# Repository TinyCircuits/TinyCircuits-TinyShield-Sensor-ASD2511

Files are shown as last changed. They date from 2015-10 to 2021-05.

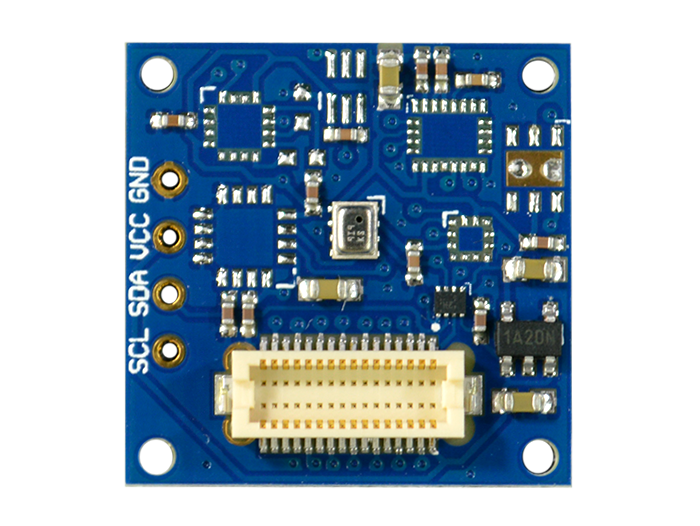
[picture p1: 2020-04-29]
images/tutorial_images_barometric-pressure/ASD2511-R-P-Tutorial-Image-01.png

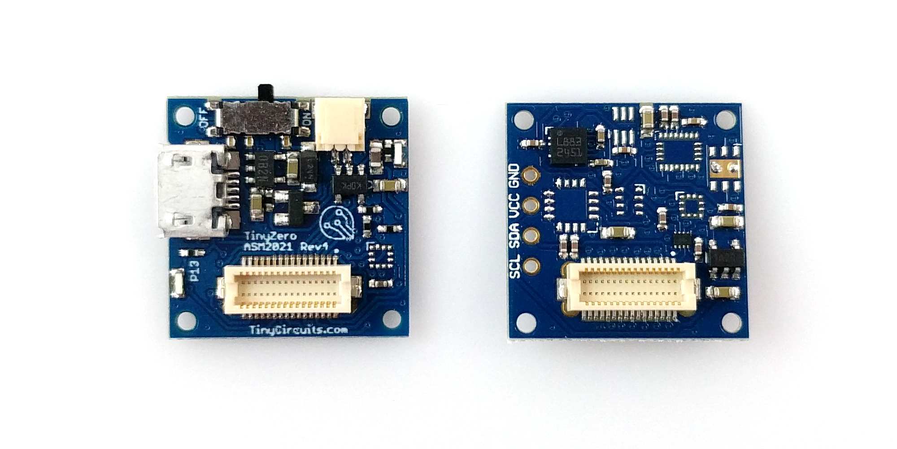
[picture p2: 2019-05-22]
images/tutorial_images_compass/ASD2511-R-C-Tutorial-Image-02.jpg

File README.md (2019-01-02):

# TinyCircuits TinyShield Sensor Board
# ASD2511 Rev5

The design files are located in the design_files/ folder for the TinyCircuits ASD2511 Rev 5 PCB.  This is a TinyShield board (Square Version, 20mm x 20mm) that has multiple sensor ICs on it and can be built under different configurations based on the sensor needs.  This board includes a 3-axis accelerometer, 3-axis gyroscope, 3-axis compass, 9-axis IMU, barometric pressure, temperature / humidity sensor, & ambient light sensor.  

Format is in Cadsoft Eagle format - Eagle version 6.2 was used for the original design.

For more infomation on this, check out the product pages for sensors at TinyCircuits.com: https://tinycircuits.com/collections/sensors/products/combo-sensor-tinyshield

#License:

Design by TinyCircuits.
All design files are released under the Creative Commons Attribution Share-Alike 3.0 License, see the following link for details: http://creativecommons.org/licenses/by-sa/3.0

All text above must be included in any redistribution or derived design

This project uses designs and concepts developed as part of the Arduino project and the LilyPad project.  The TinyCircuits design files themselves (schematics, PCB and libraries) are not directly derived from these works' design files and have been created new, however the concepts and basic architecture behind the TinyDuino and TinyLily products are derived and we thank the hard work of the organizations below for their contributions to open-source hardware:
  
Original Arduino Uno Design by Team Arduino

LilyPad Arduino Design by Leah Buechley and Sparkfun Electronics

Please support the open-source hardware community

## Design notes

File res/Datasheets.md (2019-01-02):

## Datasheets

LSM9DS1: https://www.st.com/resource/en/datasheet/lsm9ds1.pdf

Si7020: https://www.silabs.com/products/sensors/humidity/si7006-13-20-21-34

BMP280: https://ae-bst.resource.bosch.com/media/_tech/media/datasheets/BST-BMP280-DS001.pdf

TSL2572: http://ams.com/documents/20143/36005/TSL2572_DS000178_3-00.pdf/48392d43-48b1-e4cd-8272-40ab48727830

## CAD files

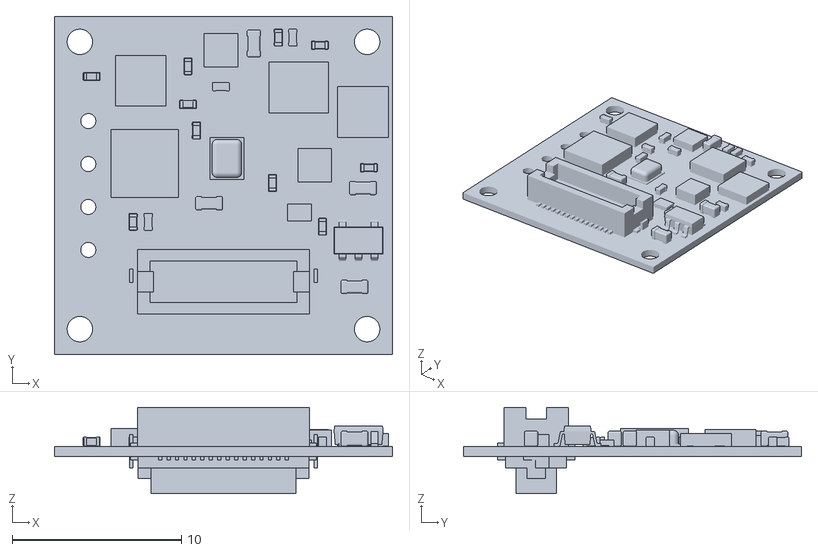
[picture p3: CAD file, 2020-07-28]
cad/TinyShield_SENSOR_BOARD_ASD2511_REV5-STL.stl
20.0 x 20.0 x 5.10

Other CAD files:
cad/TinyShield_SENSOR_BOARD_ASD2511_REV5-DETAILED_DRAWING-DXF.dxf

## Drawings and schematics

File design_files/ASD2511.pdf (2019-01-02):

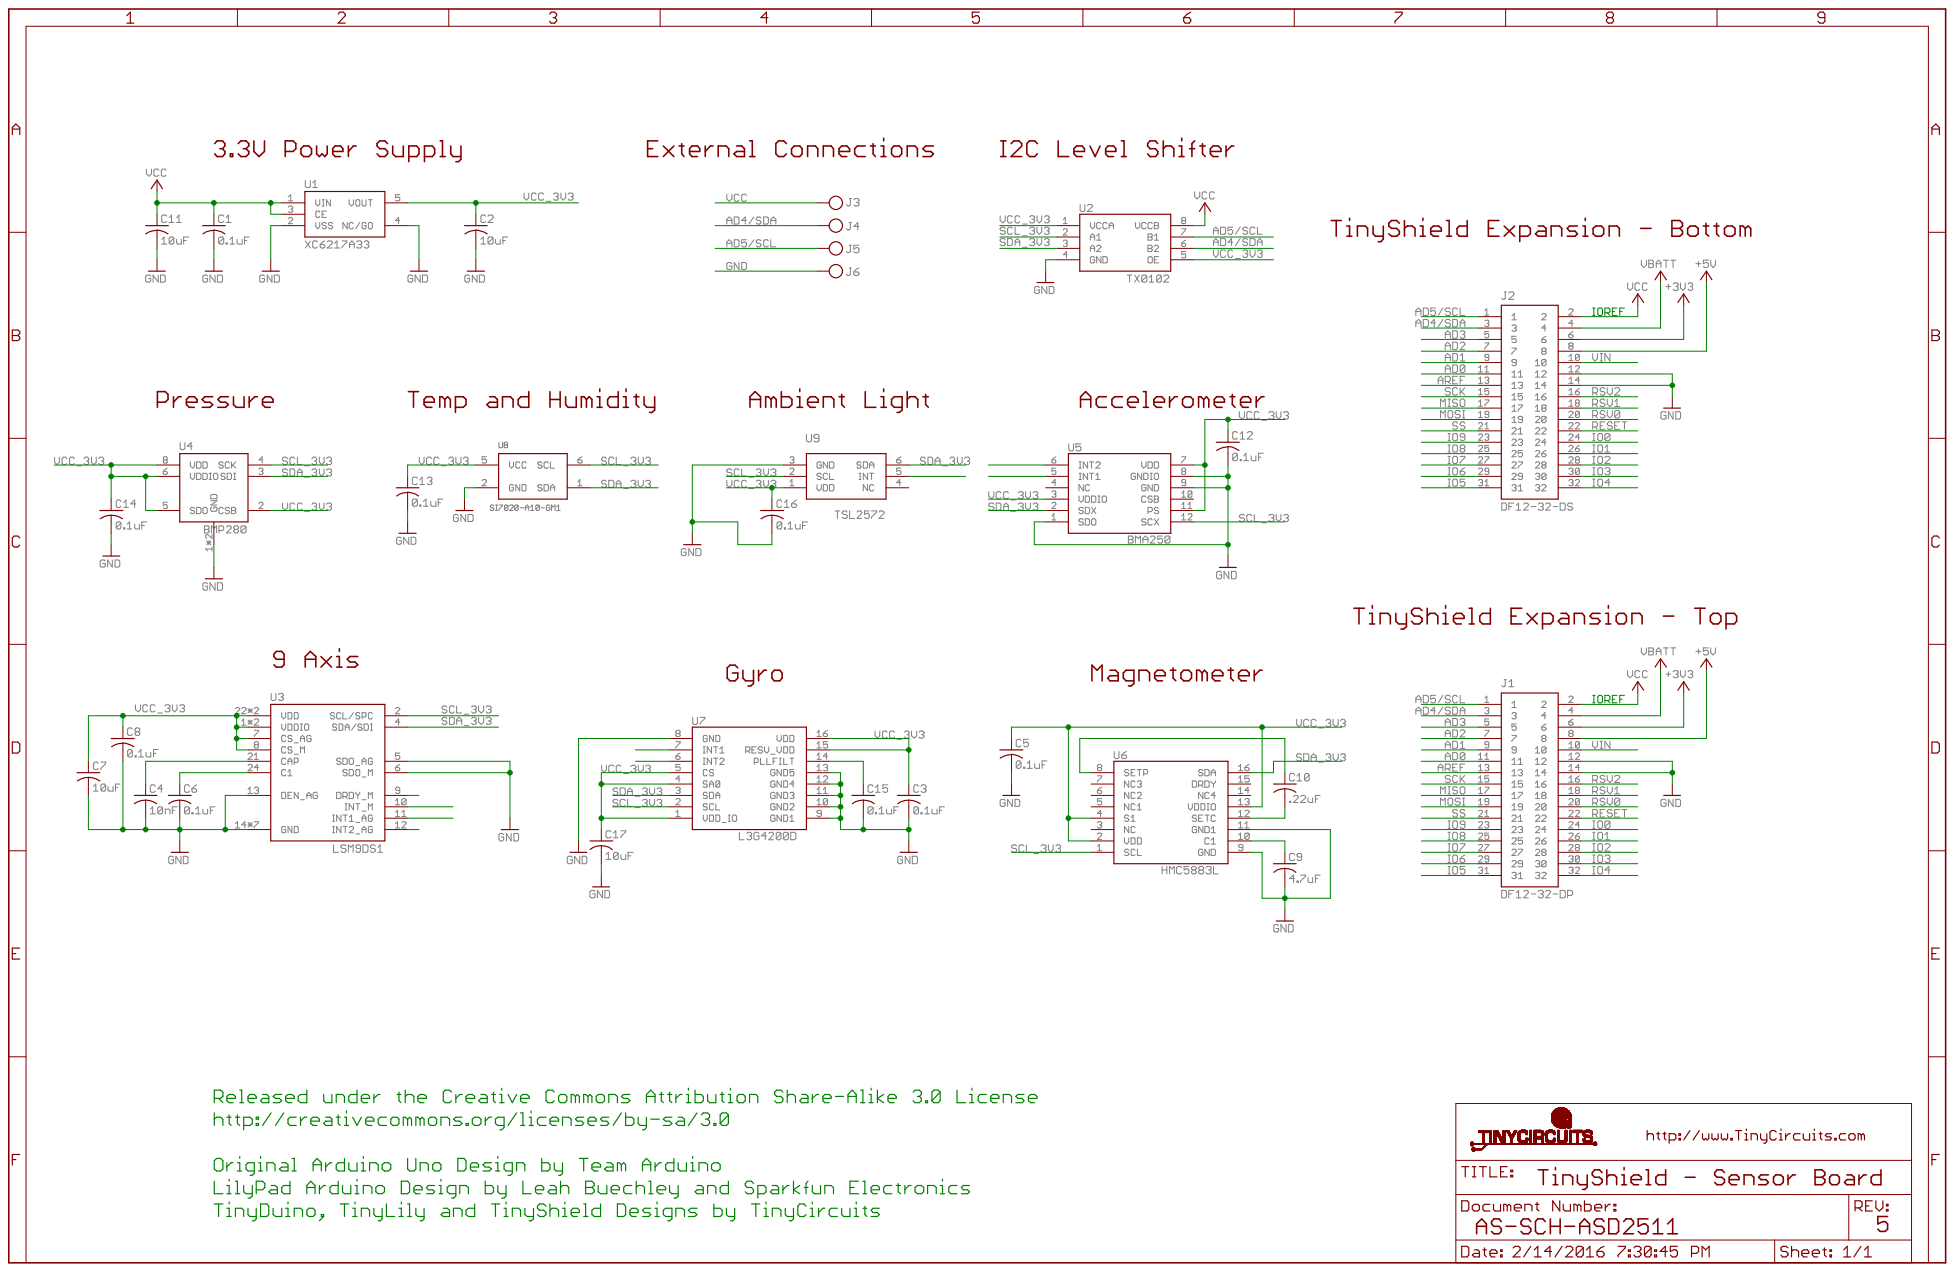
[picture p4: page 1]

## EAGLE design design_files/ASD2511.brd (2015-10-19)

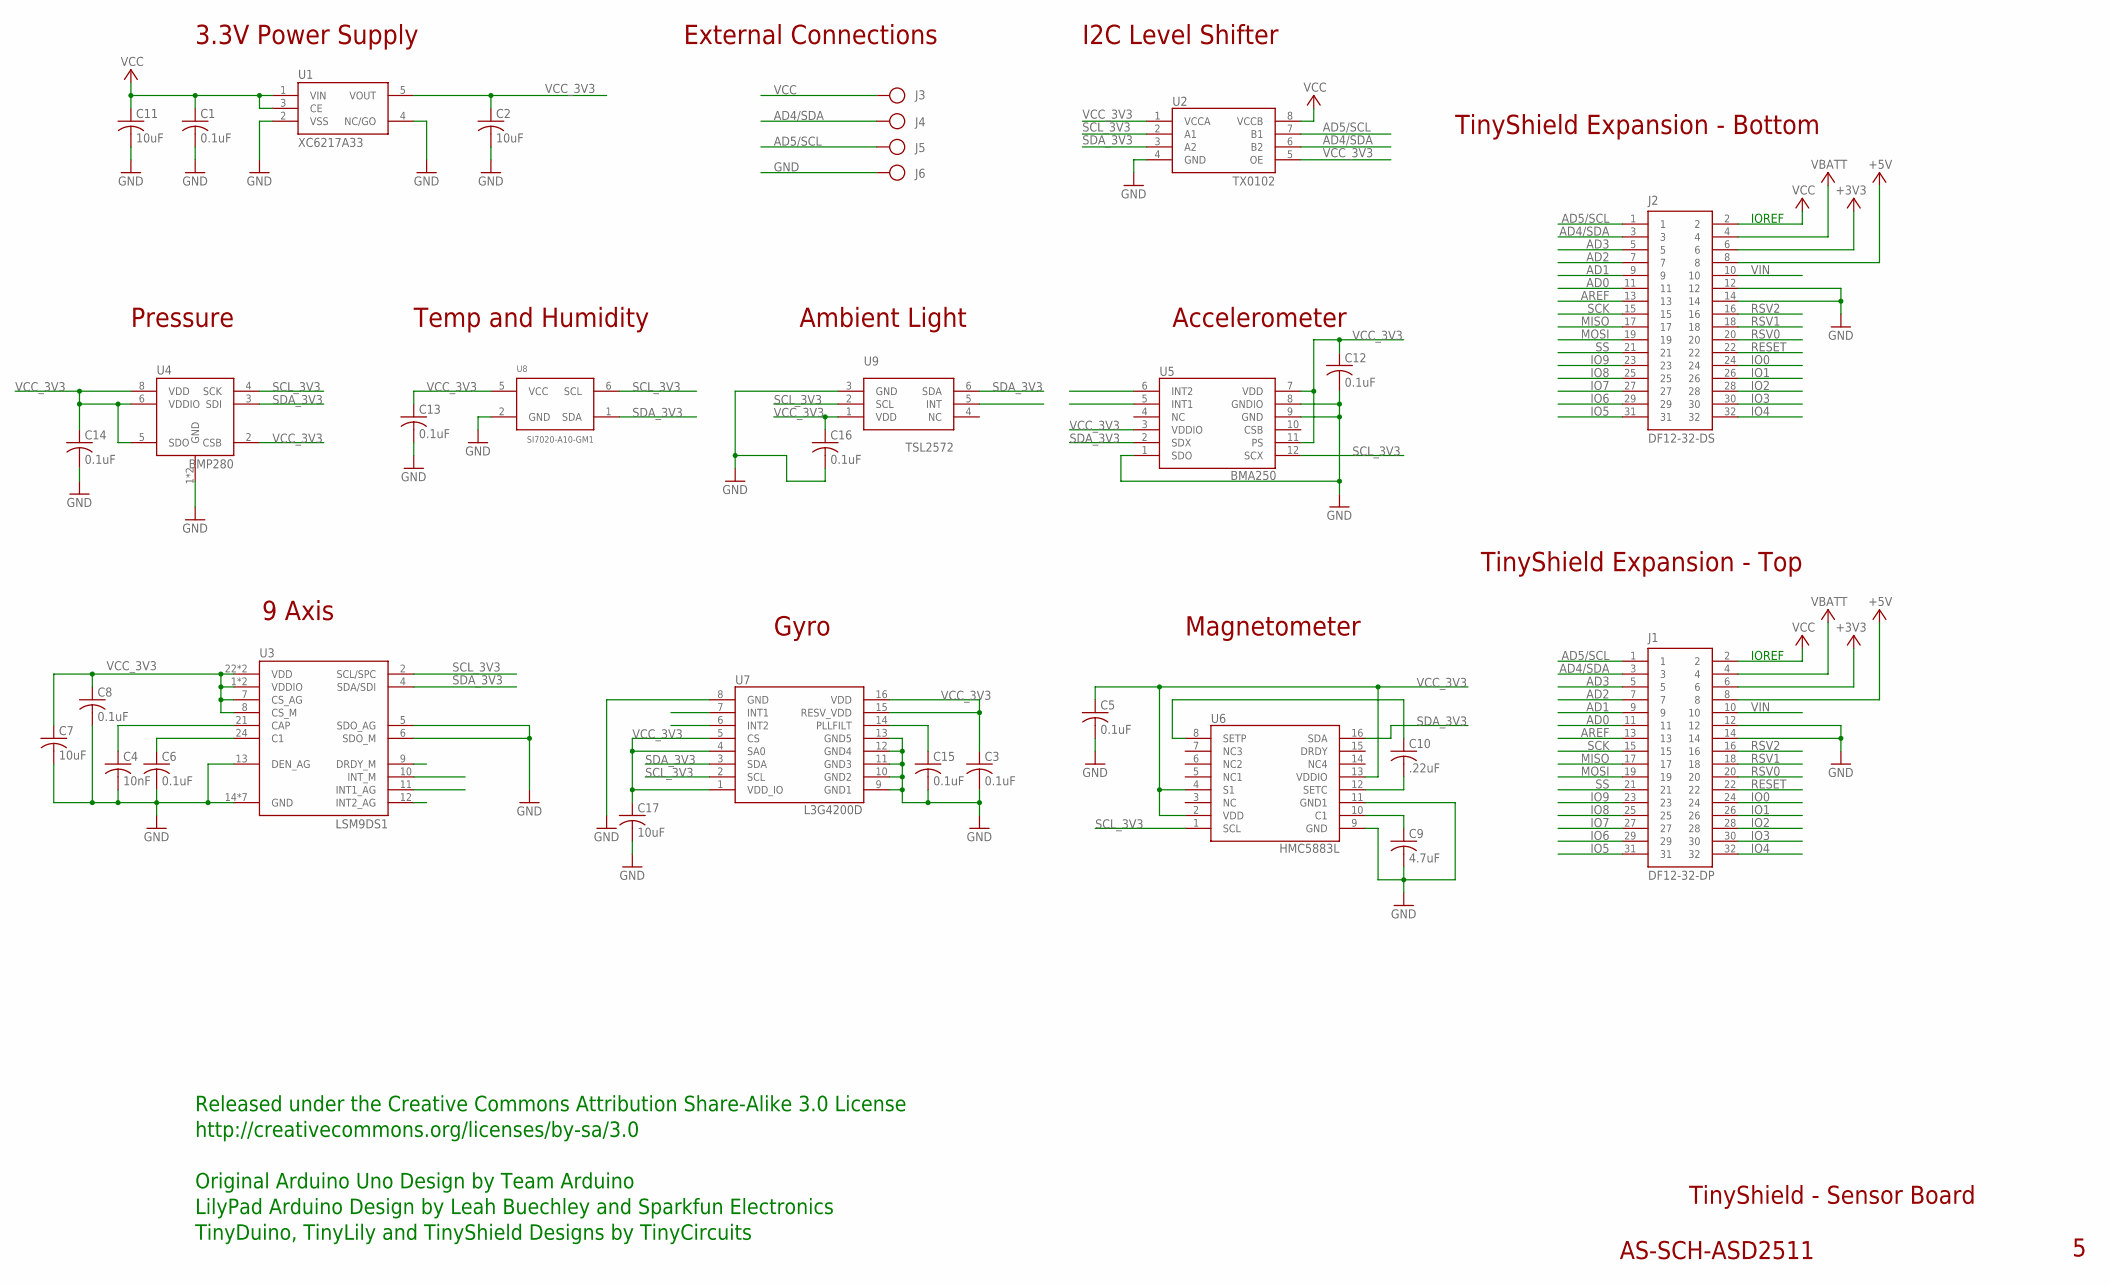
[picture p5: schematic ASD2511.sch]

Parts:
C1, C3, C5, C8, C12, C13, C14, C15, C16: 0.1uF; C0402; PARTNO AS-ITM-00008
C2, C7: 10uF; C0603; PARTNO AS-ITM-00002
C4: 10nF; C0402
C6: 0.1uF; C0402
C9: 4.7uF; C0402; PARTNO AS-ITM-00242
C10: .22uF; C0402
C11, C17: 10uF; C0603
J1: DF12-32-DP; PARTNO AS-ITM-00015
J2: DF12-32-DS; PARTNO AS-ITM-00012
J3, J4, J5, J6: PIN_1X.1"1; 1X.1"_2
U1: XC6217A33; SOT-25; PARTNO AS-ITM-00249
U2: TX0102; DQE(R-PX2SON-N8)
U3: LSM9DS1; LGA-24
U4: BMP280
U5: BMA250; 3-AXIS_ACCELEROMETER
U6: HMC5883L
U7: L3G4200D
U8: SI7020-A10-GM1; DFN6
U9: TSL2572

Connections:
+3V3: J1.6, J2.6
+5V: J1.8, J2.8
AD0: J1.11, J2.11
AD1: J1.9, J2.9
AD2: J1.7, J2.7
AD3: J1.5, J2.5
AD4/SDA: J1.3, J2.3, J4.1, U2.6 (B2)
AD5/SCL: J1.1, J2.1, J5.1, U2.7 (B1)
AREF: J1.13, J2.13
GND: C1.2, C2.2, C3.2, C4.2, C5.2, C6.2, C7.2, C8.2, C9.2, C11.2, C12.2, C13.2, C14.2, C15.2, C16.2, C17.2, J1.12, J1.14, J2.12, J2.14, J6.1, U1.2 (VSS), U1.4 (NC/GO), U2.4 (GND), U3.5 (SDO_AG), U3.6 (SDO_M), U3.13 (DEN_AG), U3.14 (GND), U3.15 (GND), U3.16 (GND), U3.17 (GND), U3.18 (GND), U3.19 (GND), U3.20 (GND), U4.1 (GND), U4.7 (GND), U5.1 (SDO), U5.8 (GNDIO), U5.9 (GND), U6.9 (GND), U6.11 (GND1), U7.8 (GND), U7.9 (GND1), U7.10 (GND2), U7.11 (GND3), U7.12 (GND4), U7.13 (GND5), U8.2 (GND), U9.3 (GND)
IO0: J1.24, J2.24
IO1: J1.26, J2.26
IO2: J1.28, J2.28
IO3: J1.30, J2.30
IO4: J1.32, J2.32
IO5: J1.31, J2.31
IO6: J1.29, J2.29
IO7: J1.27, J2.27
IO8: J1.25, J2.25
IO9: J1.23, J2.23
MISO: J1.17, J2.17
MOSI: J1.19, J2.19
unnamed: C4.1, U3.21 (CAP)
unnamed: C15.1, U7.14 (PLLFILT)
unnamed: C9.1, U6.10 (C1)
unnamed: C6.1, U3.24 (C1)
unnamed: C10.2, U6.12 (SETC)
unnamed: C10.1, U6.8 (SETP)
RESET: J1.22, J2.22
RSV0: J1.20, J2.20
RSV1: J1.18, J2.18
RSV2: J1.16, J2.16
SCK: J1.15, J2.15
SCL_3V3: U2.2 (A1), U3.2 (SCL/SPC), U4.4 (SCK), U5.12 (SCX), U6.1 (SCL), U7.2 (SCL), U8.6 (SCL), U9.2 (SCL)
SDA_3V3: U2.3 (A2), U3.4 (SDA/SDI), U4.3 (SDI), U5.2 (SDX), U6.16 (SDA), U7.3 (SDA), U8.1 (SDA), U9.6 (SDA)
SS: J1.21, J2.21
VBATT: J1.4, J2.4
VCC: C1.1, C11.1, J1.2, J2.2, J3.1, U1.1 (VIN), U1.3 (CE), U2.8 (VCCB)
VCC_3V3: C2.1, C3.1, C5.1, C7.1, C8.1, C12.1, C13.1, C14.1, C16.1, C17.1, U1.5 (VOUT), U2.1 (VCCA), U2.5 (OE), U3.1 (VDDIO), U3.3 (VDDIO), U3.7 (CS_AG), U3.8 (CS_M), U3.22 (VDD), U3.23 (VDD), U4.2 (CSB), U4.5 (SDO), U4.6 (VDDIO), U4.8 (VDD), U5.3 (VDDIO), U5.7 (VDD), U5.11 (PS), U6.2 (VDD), U6.4 (S1), U6.13 (VDDIO), U7.1 (VDD_IO), U7.4 (SA0), U7.5 (CS), U7.15 (RESV_VDD), U7.16 (VDD), U8.5 (VCC), U9.1 (VDD)
VIN: J1.10, J2.10

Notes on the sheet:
TinyShield Expansion - Bottom
TinyShield - Sensor Board
AS-SCH-ASD2511
TinyShield Expansion - Top
IOREF
Released under the Creative Commons Attribution Share-Alike 3.0 License
http://creativecommons.org/licenses/by-sa/3.0
LilyPad Arduino Design by Leah Buechley and Sparkfun Electronics
TinyDuino, TinyLily and TinyShield Designs by TinyCircuits
Original Arduino Uno Design by Team Arduino
External Connections
3.3V Power Supply
I2C Level Shifter
9 Axis
Pressure
Temp and Humidity
Ambient Light
Accelerometer
Gyro
Magnetometer

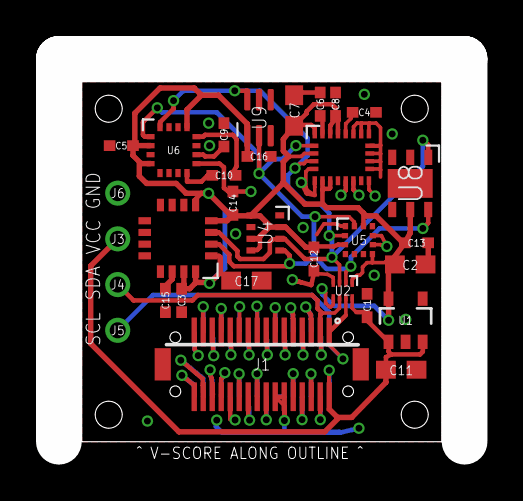
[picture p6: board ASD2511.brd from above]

Board: 2 copper layers, 20.0 x 20.0 mm, 33 parts (1 on the bottom side), 40 nets.

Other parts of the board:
U$1: DOCFIELD-TINYCIRCUITS-PCB

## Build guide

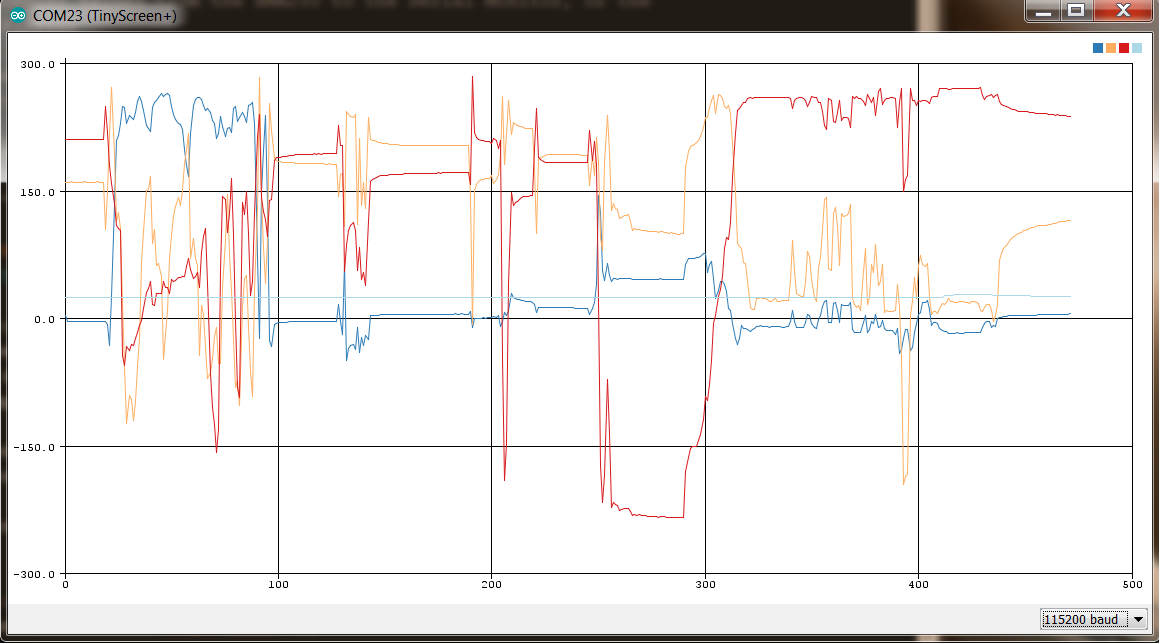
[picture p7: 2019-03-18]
images/tutorial_images_accelerometer/ASD2511-R-A-Tutorial-Image-06.png

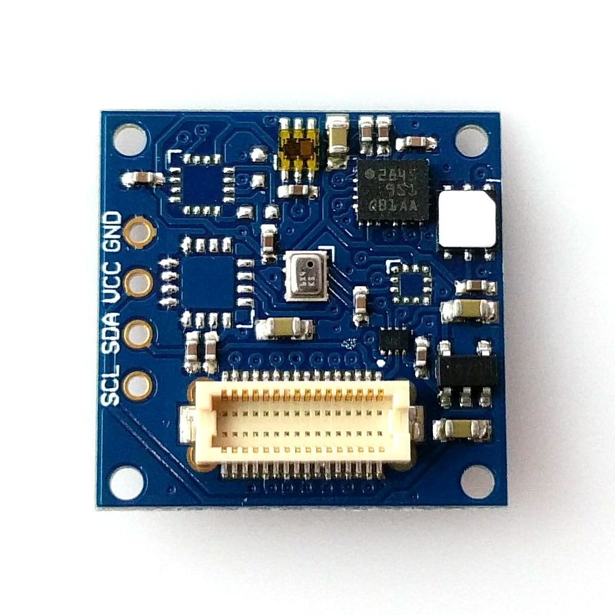
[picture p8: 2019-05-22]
images/tutorial_images_combo/ASD2511-R-N-T-P-L-Tutorial-Image-01.jpg

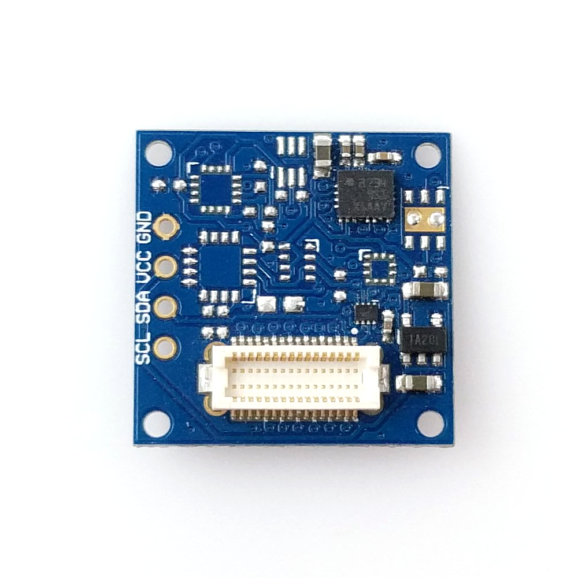
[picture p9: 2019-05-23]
images/tutorial_images_9-axis/ASD2511-R-N-Tutorial-Image-01.jpg

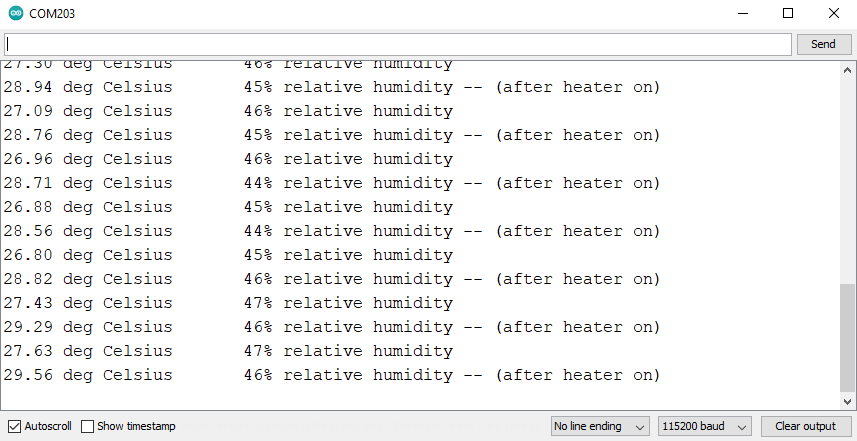
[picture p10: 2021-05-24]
images/tutorial_images_temperature-humidity/ASD2511-R-T-Tutorial-Image-05.png

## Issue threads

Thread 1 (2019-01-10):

No need to wait after Wire.requestFrom() and no need to clear the buffer.

Koepel, 2019-01-10:
In the file "TinyCircuits-TinyShield-Sensor-ASD2511/libraries/SI7021/SI7021.cpp" you may remove these lines (at the moment line 105 and 106):
```
while(Wire.available() < reglen) {
}
```
Explanation: [Common-mistakes#1](https://github.com/Koepel/How-to-use-the-Arduino-Wire-library/wiki/Common-mistakes#1)

At the LowPowerLab I have [issued the same problem](https://github.com/LowPowerLab/SI7021/issues/12), and they [fixed it](https://github.com/LowPowerLab/SI7021/blob/master/SI7021.cpp).

---

I spotted the same problem in "TinyCircuits-TinyShield-Sensor-ASD2511/examples/TinyShield_BarometricPressure/BMP280.cpp". The waiting after a `Wire.requestFrom()` can be removed (currently at line 129).

---

In the files:
 - TinyCircuits-TinyShield-Sensor-ASD2511/examples/TinyShield_9_Axis_Sensorboard/RTIMULSM9DS1.cpp
 - TinyCircuits-TinyShield-Sensor-ASD2511/examples/TinyShield_9_Axis_Sensorboard/RTIMUMPU9150.cpp
 -  TinyCircuits-TinyShield-Sensor-ASD2511/libraries/RTIMULib/RTIMUMPU9150.cpp

in the functions `I2CReadByte()` and `I2CReadBytes()`, the buffer is cleared after a Wire.endTransmission:
```
while(Wire.available())
  Wire.read();
```
Those lines can be removed as well.
Explanation: [Common-mistakes#4](https://github.com/Koepel/How-to-use-the-Arduino-Wire-library/wiki/Common-mistakes#4)

Closed 2019-01-10.

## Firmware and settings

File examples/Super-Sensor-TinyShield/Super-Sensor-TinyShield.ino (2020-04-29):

/************************************************************************
 * Combo Sensor TinyShield Example Program
 * 
 * This program utilizes all sensors on the Combo Sensor TinyShield and
 * prints the data to the Serial Monitor.
 *
 * Hardware by: TinyCircuits
 * Written by: Hunter Hykes for TinyCircuits
 *
 * Initiated: 01/14/2020
 * Updated: 01/14/2020
 ************************************************************************/

#include <Wire.h>
#include "RTIMUSettings.h"  // 9-Axis
#include "RTIMU.h"          // 9-Axis
#include "RTFusionRTQF.h"   // 9-Axis
#include <SI7021.h>         // Temp/Hum
#include "BMP280.h"         // Pressure Sensor

#ifndef ARDUINO_ARCH_SAMD
#include <EEPROM.h>
#endif

// Make compatible with all TinyCircuits processors
#if defined(ARDUINO_ARCH_AVR)
#define SerialMonitorInterface Serial
#elif defined(ARDUINO_ARCH_SAMD)
#define SerialMonitorInterface SerialUSB
#endif

// sets the rate at which results are displayed
#define DISPLAY_INTERVAL 10000    // interval between SerialMonitorInterface updates
#define  SERIAL_PORT_SPEED 115200 // defines the speed to use for the debug serial port

/* * * * * * * * * * * * 9-Axis Sensor * * * * * * * * * * * */
RTIMU *imu;               // the IMU object
RTFusionRTQF fusion;      // the fusion object
RTIMUSettings settings;   // the settings object
unsigned long lastDisplay;
unsigned long lastRate;
int sampleCount;
unsigned long delta;
unsigned long now = millis();
RTVector3 accelData;    // for storing 9-Axis accelerometer data
RTVector3 gyroData;     // for storing 9-Axis gyroscope data
RTVector3 compassData;  // for storing 9-Axis compass data
RTVector3 fusionData;   // for storing 9-Axis fusion data

/* * * * * * * * * * * Temp/Hum Sensor * * * * * * * * * * */
SI7021 sensor;        // Temp/Hum Sensor Object
int celcius;          // temperature data
int relativeHumidity; // humidity data

/* * * * * * * *  ** * Pressure Sensor * * * * * * * * * * */
#define P0 1013.25
BMP280 bmp;
bool PrintPressure = true; // if true, pressure values will be printed
double T, A, P; // temperature, altitude, and pressure value readings

/* * * * * * * * * Ambient Light Sensor * * * * * * * * * */
#define TSL2572_I2CADDR 0x39 // address of ambient light sensor

#define GAIN_1X 0
#define GAIN_8X 1
#define GAIN_16X 2
#define GAIN_120X 3

#define GAIN_DIVIDE_6 true //only use this with 1x and 8x gain settings
int gain_val = 0;

float AmbientLightLux;  // Illuminance value reading


void setup() {
  imu = RTIMU::createIMU(&settings);  // 9-Axis object

  SerialMonitorInterface.begin(SERIAL_PORT_SPEED); // Setup the Serial Monitor to operate at the specified Baud rate
  while (!SerialMonitorInterface); // do nothing until the Serial Monitor is opened

  Wire.begin(); // start I2C communications

  init9axis();          // initialize the 9-axis sensor
  initTempSensor();     // initialize the temperature and humidity sensor
  initPressSensor();    // initialize the pressure sensor
  TSL2572init(GAIN_1X); // initialize the illuminance sensor

  SerialMonitorInterface.println("\n- - - - - - - - - - - - - - - - - - - - - - - - - - - - - -");
  SerialMonitorInterface.println("\t\t\tEND OF SETUP\t\t\t");
  SerialMonitorInterface.println("- - - - - - - - - - - - - - - - - - - - - - - - - - - - - -");
}

void loop() {
  /* * * * * * * * * * 9-Axis * * * * * * * * * */
  read9axis();
  //printAccel();
  //printGyro();
  //printMag();
  printFused();

  /* * * * * * * * * * Temp/Hum * * * * * * * * * */
  readTempSensor();
  printTempSensor();

  /* * * * * * * * * * Pressure * * * * * * * * * */
  readPressSensor();

  /* * * * * * * * * * Light * * * * * * * * * */
  AmbientLightLux = Tsl2572ReadAmbientLight();
  printLight();

  SerialMonitorInterface.println("\n- - - - - - - - - - - - - - - - - - - - - - - - - - - - - -\n");

  //delay(DISPLAY_INTERVAL); // wait some predetermined time before printing the next set of samples
}

// initialize the 9-Axis sensor
void init9axis() {
  int errcode;

  SerialMonitorInterface.print("Initializing 9-Axis..."); SerialMonitorInterface.println(imu->IMUName());
  if ((errcode = imu->IMUInit()) < 0) {
    SerialMonitorInterface.print("\t9-Axis Init Failed!"); SerialMonitorInterface.println(errcode);
  }

  if (imu->getCalibrationValid())
    SerialMonitorInterface.println("\tUsing compass calibration");
  else
    SerialMonitorInterface.println("\tNo valid compass calibration data");

  lastDisplay = lastRate = millis();
  sampleCount = 0;

  // Slerp power controls the fusion and can be between 0 and 1
  // 0 means that only gyros are used, 1 means that only accels/compass are used
  // In-between gives the fusion mix.
  fusion.setSlerpPower(0.02);

  // use of sensors in the fusion algorithm can be controlled here
  // change any of these to false to disable that sensor
  fusion.setGyroEnable(true);
  fusion.setAccelEnable(true);
  fusion.setCompassEnable(true);
}

// read values from 9-Axis and update variables
void read9axis() {
  now = millis();

  if (imu->IMURead()) {                                // get the latest data if ready yet
    fusion.newIMUData(imu->getGyro(), imu->getAccel(), imu->getCompass(), imu->getTimestamp());
    sampleCount++;
    if ((delta = now - lastRate) >= 1000) {
      SerialMonitorInterface.print("Sample rate: "); SerialMonitorInterface.print(sampleCount);
      if (imu->IMUGyroBiasValid())
        SerialMonitorInterface.println(", gyro bias valid");
      else
        SerialMonitorInterface.println(", calculating gyro bias - don't move IMU!!");

      sampleCount = 0;
      lastRate = now;
    }

    accelData = imu->getAccel();
    gyroData = imu->getGyro();
    compassData = imu->getCompass();
    fusionData = fusion.getFusionPose();
  }
}

// initialize the temperature/humidity sensor
void initTempSensor() {
  SerialMonitorInterface.println("Initializing Temp/Hum Sensor... ");
  if (!sensor.begin()) {
    SerialMonitorInterface.println("\tSI7021 Init Failed!");
    while (true);
  }
  SerialMonitorInterface.println("\tSuccess!");
}

// read values from temperature/humidity sensor and update variables
void readTempSensor() {
  celcius = sensor.getCelsiusHundredths() / 100;
  relativeHumidity = sensor.getHumidityPercent();
}

// print temperature/humidity sensor variables to SerialMonitorInterface
void printTempSensor() {
  SerialMonitorInterface.println("\nTEMPERATURE DATA");
  SerialMonitorInterface.print(celcius);
  SerialMonitorInterface.print("°C\t");
  SerialMonitorInterface.print(relativeHumidity);
  SerialMonitorInterface.println("% Humidity");
}

// print 9-Axis accelerometer values to SerialMonitorInterface
void printAccel() {
  SerialMonitorInterface.println("\nACCELEROMETER DATA");
  displayAxis("Accel: ", accelData.x(), accelData.y(), accelData.z());        // accel data
}

// print 9-Axis gyroscope values to SerialMonitorInterface
void printGyro() {
  SerialMonitorInterface.println("\nGYROSCOPE DATA");
  displayAxis("Gyro: ", gyroData.x(), gyroData.y(), gyroData.z());            // gyro data
}

// print 9-Axis magnetometer values to SerialMonitorInterface
void printMag() {
  SerialMonitorInterface.println("\nMAGNETOMETER DATA");
  displayAxis("Mag: ", compassData.x(), compassData.y(), compassData.z());    // compass data
}

// print 9-Axis fused data values to SerialMonitorInterface
void printFused() {
  SerialMonitorInterface.println("\nFUSED DATA");
  displayDegrees("Pose: ", fusionData.x(), fusionData.y(), fusionData.z());   // fused output
}

// prints the specified data label followed by the provided x, y, z values
void displayAxis(const char *label, float x, float y, float z) {
  SerialMonitorInterface.print(label);
  SerialMonitorInterface.print("\tx: "); SerialMonitorInterface.println(x);
  SerialMonitorInterface.print("\ty: "); SerialMonitorInterface.println(y);
  SerialMonitorInterface.print("\tz: "); SerialMonitorInterface.println(z);
}

// prints the specified data label followed by the provided x, y, z values (but in degrees)
void displayDegrees(const char *label, float x, float y, float z) {
  SerialMonitorInterface.print(label);
  SerialMonitorInterface.print("\tx: "); SerialMonitorInterface.println(x * RTMATH_RAD_TO_DEGREE);
  SerialMonitorInterface.print("\ty: "); SerialMonitorInterface.println(y * RTMATH_RAD_TO_DEGREE);
  SerialMonitorInterface.print("\tz: "); SerialMonitorInterface.println(z * RTMATH_RAD_TO_DEGREE);
}

// initialize the pressure sensor
void initPressSensor() {
  SerialMonitorInterface.println("Initializing Pressure Sensor... ");

  if (!bmp.begin()) {
    SerialMonitorInterface.println("\tBMP Init Failed!");
    while (1);
  }
  else SerialMonitorInterface.println("\tSuccess!");

  bmp.setOversampling(4);
}

// read values from pressure sensor and update variables
void readPressSensor() {
  char result = bmp.startMeasurment();

  if (result != 0) {
    delay(result);
    result = bmp.getTemperatureAndPressure(T, P);

    if (result != 0) {
      A = bmp.altitude(P, P0);

      printPressSensorPressure();
      printPressSensorTemperature();
      printPressSensorAltitude();
    } else {
      int debug = bmp.getError();
      SerialMonitorInterface.println(String(debug));
    }
  } else {
    SerialMonitorInterface.println("\nPressure Sensor Error.");
  }
}

// print barometric pressure value to SerialMonitorInterface
void printPressSensorPressure() {
  SerialMonitorInterface.println("\nPRESSURE DATA");
  SerialMonitorInterface.print("P = "); SerialMonitorInterface.print(P, 2); SerialMonitorInterface.println(" mBar\t");
}

// print temperature value (from pressure sensor) to SerialMonitorInterface
void printPressSensorTemperature() {
  SerialMonitorInterface.println("\nTEMPERATURE DATA (PRESSURE SENSOR)");
  SerialMonitorInterface.print("T = "); SerialMonitorInterface.print(T, 2); SerialMonitorInterface.println("°C\t");
}

// print altitude value to SerialMonitorInterface
void printPressSensorAltitude() {
  SerialMonitorInterface.println("\nALTITUDE DATA");
  SerialMonitorInterface.print("A = "); SerialMonitorInterface.print(A, 2); SerialMonitorInterface.println(" m");
}

// initialize the ambient light sensor
void TSL2572init(uint8_t gain) {
  Tsl2572RegisterWrite( 0x0F, gain );//set gain
  Tsl2572RegisterWrite( 0x01, 0xED );//51.87 ms
  Tsl2572RegisterWrite( 0x00, 0x03 );//turn on
  if (GAIN_DIVIDE_6)
    Tsl2572RegisterWrite( 0x0D, 0x04 );//scale gain by 0.16
  if (gain == GAIN_1X)gain_val = 1;
  else if (gain == GAIN_8X)gain_val = 8;
  else if (gain == GAIN_16X)gain_val = 16;
  else if (gain == GAIN_120X)gain_val = 120;
}

// writes the specified byte to the specified address of the TSL2572
void Tsl2572RegisterWrite( byte regAddr, byte regData ) {
  Wire.beginTransmission(TSL2572_I2CADDR);
  Wire.write(0x80 | regAddr);
  Wire.write(regData);
  Wire.endTransmission();
}

// read values from ambient light sensor and update variable
float Tsl2572ReadAmbientLight() {
  uint8_t data[4];
  int c0, c1;
  float lux1, lux2, cpl;

  Wire.beginTransmission(TSL2572_I2CADDR);
  Wire.write(0xA0 | 0x14);
  Wire.endTransmission();
  Wire.requestFrom(TSL2572_I2CADDR, 4);
  for (uint8_t i = 0; i < 4; i++)
    data[i] = Wire.read();

  c0 = data[1] << 8 | data[0];
  c1 = data[3] << 8 | data[2];

  //see TSL2572 datasheet
  cpl = 51.87 * (float)gain_val / 60.0;
  if (GAIN_DIVIDE_6) cpl /= 6.0;
  lux1 = ((float)c0 - (1.87 * (float)c1)) / cpl;
  lux2 = ((0.63 * (float)c0) - (float)c1) / cpl;
  cpl = max(lux1, lux2);
  return max(cpl, 0.0);
}

// print illuminance value to SerialMonitorInterface
void printLight() {
  SerialMonitorInterface.println("\nILLUMINANCE DATA");
  SerialMonitorInterface.print(AmbientLightLux);
  SerialMonitorInterface.println(" lux");
}

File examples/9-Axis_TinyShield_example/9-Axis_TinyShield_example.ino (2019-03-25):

/*
  TinyCircuits LSM9DS1 9 Axis TinyShield Example Sketch
  
  This demo is intended for the ASD2511 Sensor Board TinyShield with a LSM9DS1
  9 axis sensor populated. It shows basic use of a modified RTIMULib with the
  sensor.
  
  This program now includes an EEPROM compatibility file for TinyScreen+.
  Using it will lock the last 16KB of flash for EEPROM emulation and prevent
  the bootloader from erasing or writing that section. This should not affect
  other programs unless they are trying to use the last 16KB of flash.

  Written 11 July 2016
  By Ben Rose
  Modified 07 January 2019
  By Hunter Hykes

  https://TinyCircuits.com
*/

////////////////////////////////////////////////////////////////////////////
//
//  This file is part of RTIMULib-Arduino
//
//  Copyright (c) 2014-2015, richards-tech
//
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
////////////////////////////////////////////////////////////////////////////


#include <Wire.h>
#include "RTIMUSettings.h"
#include "RTIMU.h"
#include "RTFusionRTQF.h"
#ifndef ARDUINO_ARCH_SAMD
#include <EEPROM.h>
#endif

RTIMU *imu;                                           // the IMU object
RTFusionRTQF fusion;                                  // the fusion object
RTIMUSettings settings;                               // the settings object

//  DISPLAY_INTERVAL sets the rate at which results are displayed

#define DISPLAY_INTERVAL  300                         // interval between pose displays

//  SERIAL_PORT_SPEED defines the speed to use for the debug serial port

#define  SERIAL_PORT_SPEED  115200

#if defined(ARDUINO_ARCH_SAMD)
  #define SerialMonitor SerialUSB
#else
  #define SerialMonitor Serial
#endif

unsigned long lastDisplay;
unsigned long lastRate;
int sampleCount;

void setup()
{
    int errcode;
  
    SerialMonitor.begin(SERIAL_PORT_SPEED);
    while(!SerialMonitor);
    
    Wire.begin();
    imu = RTIMU::createIMU(&settings);                        // create the imu object
  
    SerialMonitor.print("ArduinoIMU starting using device "); SerialMonitor.println(imu->IMUName());
    if ((errcode = imu->IMUInit()) < 0) {
        SerialMonitor.print("Failed to init IMU: "); SerialMonitor.println(errcode);
    }

    if (imu->getCalibrationValid())
        SerialMonitor.println("Using compass calibration");
    else
        SerialMonitor.println("No valid compass calibration data");

    lastDisplay = lastRate = millis();
    sampleCount = 0;

    // Slerp power controls the fusion and can be between 0 and 1
    // 0 means that only gyros are used, 1 means that only accels/compass are used
    // In-between gives the fusion mix.
    
    fusion.setSlerpPower(0.02);
    
    // use of sensors in the fusion algorithm can be controlled here
    // change any of these to false to disable that sensor
    
    fusion.setGyroEnable(true);
    fusion.setAccelEnable(true);
    fusion.setCompassEnable(true);
}

void loop()
{  
  unsigned long now = millis();
  unsigned long delta;
  
  if (imu->IMURead()) {                                // get the latest data if ready yet
    fusion.newIMUData(imu->getGyro(), imu->getAccel(), imu->getCompass(), imu->getTimestamp());
    sampleCount++;
    if ((delta = now - lastRate) >= 1000) {
      SerialMonitor.print("Sample rate: "); SerialMonitor.print(sampleCount);
      if (imu->IMUGyroBiasValid())
        SerialMonitor.println(", gyro bias valid");
      else
        SerialMonitor.println(", calculating gyro bias - don't move IMU!!");
        
      sampleCount = 0;
      lastRate = now;
    }
    if ((now - lastDisplay) >= DISPLAY_INTERVAL) {
      lastDisplay = now;
      RTVector3 accelData=imu->getAccel();
      RTVector3 gyroData=imu->getGyro();
      RTVector3 compassData=imu->getCompass();
      RTVector3 fusionData=fusion.getFusionPose();
      //displayAxis("Accel:", accelData.x(), accelData.y(), accelData.z());        // accel data
      //displayAxis("Gyro:", gyroData.x(), gyroData.y(), gyroData.z());            // gyro data
      //displayAxis("Mag:", compassData.x(), compassData.y(), compassData.z());    // compass data
      displayDegrees("Pose:", fusionData.x(), fusionData.y(), fusionData.z());   // fused output
      SerialMonitor.println();
    }
  }
}

void displayAxis(const char *label, float x, float y, float z)
{
  SerialMonitor.print(label);
  SerialMonitor.print(" x:"); SerialMonitor.print(x);
  SerialMonitor.print(" y:"); SerialMonitor.print(y);
  SerialMonitor.print(" z:"); SerialMonitor.print(z);
}

void displayDegrees(const char *label, float x, float y, float z)
{
  SerialMonitor.print(label);
  SerialMonitor.print(" x:"); SerialMonitor.print(x * RTMATH_RAD_TO_DEGREE);
  SerialMonitor.print(" y:"); SerialMonitor.print(y * RTMATH_RAD_TO_DEGREE);
  SerialMonitor.print(" z:"); SerialMonitor.print(z * RTMATH_RAD_TO_DEGREE);
}

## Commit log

2017-03-22 Added sample sketches
2019-01-02 update format
    [ASD2511.brd, ASD2511.sch]
2019-01-11 fixed pressure sensor image
2019-03-15 Add accelerometer stuff
2019-05-23 oops, wrong board!
2020-01-10 add combination example of combo sensors
2020-01-17 guess I didn't push this
    [Accelerometer_TinyShield_example.ino, BMP280.cpp, Barometric-Pressure_TinyShield_example.ino]
2020-04-29 Negative pressure fix by Willem - thanks!
    [BMP280.cpp]
2020-07-28 Add CAD data
    [TinyShield_SENSOR_BOARD_ASD2511_REV5-DETAILED_DRAWING-DXF.dxf, TinyShield_SENSOR_BOARD_ASD2511_REV5-STL.stl]
2020-08-14 Update CAD drawing
    [TinyShield_SENSOR_BOARD_ASD2511_REV5-DETAILED_DRAWING-DXF.dxf]
